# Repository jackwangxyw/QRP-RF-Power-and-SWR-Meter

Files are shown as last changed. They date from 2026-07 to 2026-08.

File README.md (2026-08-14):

# QRP RF Power and SWR Meter

This is a compact standalone power and SWR meter designed for field use. The rectifier diodes used in this design have relatively flat performance up to 50MHz, so it is able to cover all of the HF bands. It is built around the ATtiny 3224 microcontroller, so writing your own or modifying the existing code is easy. 

Render Main
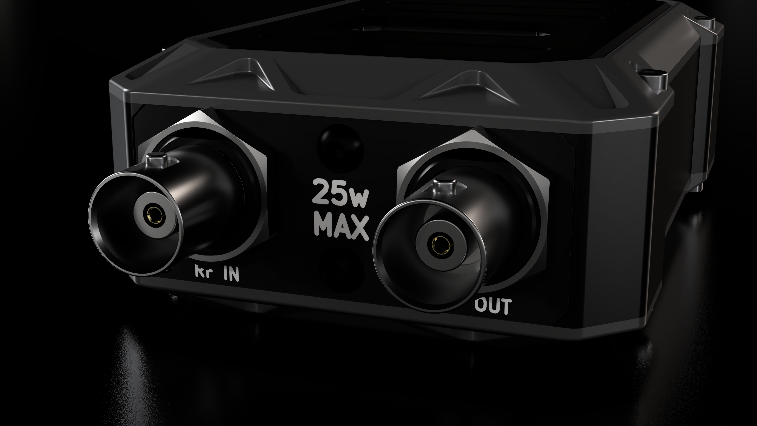
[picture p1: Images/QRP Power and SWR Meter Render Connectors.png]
Render Connectors


## Features

- Accurate Power and SWR measurements for HF + 6m
- 0.96in OLED display
  - Numerical and graph views for power and SWR
  - Peak hold indicator on power bar
- 25w max power limit
- Built in 1000mAh battery for over 40 hours of continuous use, 120 hours of realistic field use, and months on standby
- Auto dim, screen off, and standby modes, turned on by RF
- USB-C charging
  - LED turns on when charging, and will turn off when full
  - Can charge while the switch is in the off position
- Reverse polarity protection for the battery
- Watts or dBm display
- Built in calibration mode (Displays raw ADC counts, more info below)
- Basic warning features
  - When SWR or power goes over a certain threshold, that number will blink as a warning.

## Changelog
Rev 2 - Switched to the ATtiny 3224 microcontroller from the old and obsolete ATmega 328p, switched to a 4 layer board, added onboard lipo charging, connectorized the OLED, among various other small improvements.

## Usage
To use the meter, simply flip the switch to the on position, plug in your RF input and output, and you're off to the races. If you want to switch the unit for power measurements between Watts and dBm, simply short press the tactile button. When no RF is passed through the meter, the screen will dim, then turn off, then go into standby mode in intervals set in the [Code/SRC/config.h](Code/SRC/config.h) file. Passing RF through the meter will turn the screen back on and put it into active mode. (Note that the button does nothing when the screen is off.) You can also slide the switch off and back on again to put the device back into active mode as well. This feature is just an auto standby, not a true auto off, that is handled with the physical slide switch.

When the device is turned on via the switch, a splash screen shows indicating the software version and battery voltage. Then it jumps to the main screen. 

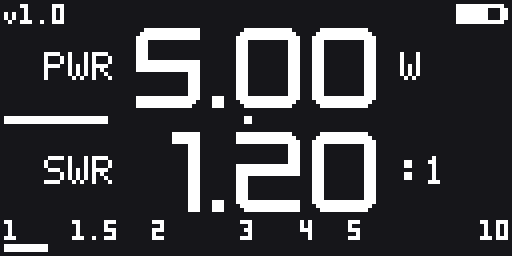
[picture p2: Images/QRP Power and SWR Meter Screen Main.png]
Main screen


## Calibration
This board has a built in calibration mode that you can enter by long pressing the tactile button on the PCB. This mode will display the raw adc counts for the VFWD and VREV that the microcontroller reads. To be clear, you **DO NOT** need to do this in normal use, the default values in the code have already been tested and are accurate. Only do this if you have the precision equipment to do so and want to gain that last 1-5% of accuracy. (That accuracy will probably be gone anyway as the diodes' responses vary with temperature and other factors anyway). You can also check the resting VFWD count of WAKE_COUNTS in [Code/SRC/config.h](Code/SRC/config.h). The default value should work, but if you notice your value is higher than the default, the device will never go into standby, so you can change that.

If you notice that your values are off by a consistent amount at every power level, you can change the CAL_OFFSET_DB in [Code/SRC/config.h](Code/SRC/config.h). (Again, this is **NOT NEEDED** for most people, only for the edge cases where that batch of diodes may be off) (Only do this if you notice something consistently wrong when comparing with precision equipment)

To calibrate the power measurements, take a RF source of known power output and frequency and plug this into the RF input, plug a dummy load into the RF output, transmit at many different power levels, record the VFWD ADC count and the power you inputted (in dBm) for every datapoint.(adc counts is x, dBm power is y) Take the values you get and input them into [Desmos](https://www.desmos.com/calculator) in a table, then run a quartic regression: y1 ~ a(log(x1))^4 + b(log(x1))^3 + c(log(x1))^2 + d·log(x1) + k. Take the a, b, c, d, and k values you obtain and input them in CAL_A through CAL_K in [Code/SRC/config.h](Code/SRC/config.h). This "calibration factor" will work for both power and SWR readings. 

There are two hard limits with this hardware. The bottom limit is set by the 1N5711 rectifier diodes. They need ~0.33 V to conduct, so below ~0.25 W, readings will be inaccurate, power levels under ~0.1 W will read as 0. The top end limit is set at an ABSOLUTE max of 28.7 W, this is due to the 2.5v adc reference and maximum of 4095 ADC counts.

If you want to test SWR, you can put loads of known resistance on the RF output to check the reported value. (Eg: 50Ω = 1:1 100Ω = 2:1, 150Ω = 3:1, etc)

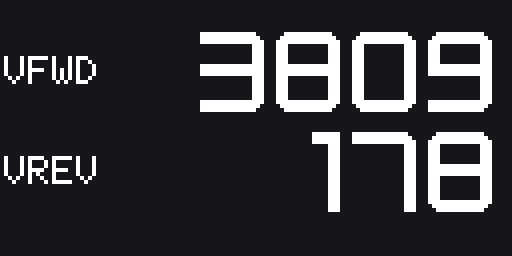
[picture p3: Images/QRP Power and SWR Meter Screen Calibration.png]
Calibration screen


## Assembly
Assembly is quite simple. All of the SMD parts are 0805 size or smaller so it is easy to hand solder without a hot plate. There are plenty of tutorials on how to do this online. Some tips that I can give are to use LOTS of flux. (Seriously, this makes life so much easier) Simply solder all of the parts onto the PCB. When you solder the connector to the OLED display, make sure to double check the pinout of your specific display and match it to the PCB silkscreen. Some of the displays may have different pinouts. 

There is also an [interactive BOM](Interactive%20BOM.html) which helps greatly with locating where parts go. Simply download the file to your computer, then simply opening the file will open up the interactive BOM in your web browser.

If you do decide to use the 3D printed case, simply put in the 8 heat set inserts on each side, and screw everything together, its pretty self explanatory. You may want to attach the battery to the top panel with some glue or double sided tape to prevent it from sliding/rattling around inside of the case.

## Programming

Programming is easy, all you need is a [UPDI programmer](https://www.adafruit.com/product/5879?srsltid=AfmBOoosIHZ5qCXL0qs-41c_Th3voxFLiswGlyJfjmZCHLlL7hfAid7V) and a computer. Simply plug the programmer into your computer, connect the programmer's 3 pins into the PCB, and use PlatformIO to flash the board. The MCU runs at 10MHz because the ATtiny is only rated for 20MHz with a VDD above 4.5 V.

For the user interface, there are two fonts available to pick from in the [Code/SRC/config.h](Code/SRC/config.h) file. You can change BIG_FONT between two font styles, choose whichever one suits your liking.

For REV 2 PCBs, the screen is software I2C because I totally missed the fact that the ATtiny supports hardware I2C and put them on the wrong pins. This works fine, but will likely be fixed in a future PCB revision.

```
cd Code
pio run            # build
pio run -t upload  # flash over UPDI
```

## Ordering PCBs
This design needs 1 or 2 pcbs depending on whether or not you build the 3D printed enclosure. You will need the Main PCB and the optional Connector Panel PCB. The gerber files found for these are in the [Gerbers Folder](Gerbers). I like to order from JLCPCB as they have good quality and are relatively cheap, I got 5 of each of these PCBs for under $20 shipped. The Main PCB is a 4 layer PCB and needs the JLC04161H-7628 stackup or similar. The connector panel is just a normal 2 layer PCB. Everything else can be the JLCPCB defaults. (You can change the solder mask color to whatever suits your preference)
## BOM
A [CSV](RF%20SWR%20and%20Power%20Meter%20BOM.csv) file is included with all of the parts, specs and links. One of these meters can be built for anywhere between $30-$50 each depending on where you live and what parts you have already and how many you decide to build.   

PCB parts:
| Reference | Qty | Value | Footprint | Recommended Part |
| :--- | :---: | :--- | :--- | :--- |
| C1, C2 | 2 | 10nF | 805 | [DigiKey Link](https://www.digikey.com/en/products/detail/kyocera-avx/KGM21NR71H103KT/563493) |
| C3, C4 | 2 | 4.7uF | 805 | [DigiKey Link](https://www.digikey.com/en/products/detail/tdk/C2012X7R1E475K125AB/2443450) |
| C5 | 1 | 0.1uF | 805 | [DigiKey Link](https://www.digikey.com/en/products/detail/kyocera-avx/KGM21NR71H104KT/563505) |
| D1, D2 | 2 | 1N5711 | SOD-123 | [DigiKey Link](https://www.digikey.com/en/products/detail/good-ark-semiconductor/GS1N5711W/18667513) |
| D3 | 1 | LED Red | 1206 | [DigiKey Link](https://www.digikey.com/en/products/detail/liteon/LTST-C150KRKT/386761) |
| IC1 | 1 | ATTINY3224 | SOIC-14 | [DigiKey Link](https://www.digikey.com/en/products/detail/microchip-technology/ATTINY3224-SSFR/17631056) |
| IC2 | 1 | MCP73831 | SOT-23-5 | [DigiKey Link](https://www.digikey.com/en/products/detail/microchip-technology/MCP73831T-2ACI-OT/964301) |
| J1, J2 | 2 | BNC Connector | Molex 0731385003 | [DigiKey Link](https://www.digikey.com/en/products/detail/molex/0731385003/3303300) |
| J3 | 1 | USBC Receptacle | GCT_USB4800-03-A | [DigiKey Link](https://www.digikey.com/en/products/detail/gct/USB4800-03-A/16688032) |
| J4 | 1 | OLED Connector | JST B4B-XH-A | [DigiKey Link](https://www.digikey.com/en/products/detail/jst-sales-america-inc/B4B-XH-A/1651047) |
| J5 | 1 | UPDI Connector | 3 Pin 2.54mm Header | [DigiKey Link](https://www.digikey.com/en/products/detail/sullins-connector-solutions/PPPC031LFBN-RC/810175) |
| J6 | 1 | Battery Connector | Molex 0530480210 | [DigiKey Link](https://www.digikey.com/en/products/detail/molex/0530480210/242864) |
| Q1 | 1 | SI2301 | SOT-23-3 | [DigiKey Link](https://www.digikey.com/en/products/detail/mcc-micro-commercial-components/SI2301-TP/1793242) |
| R1, R2, R5, R6 | 4 | Thin Film 100R 1% | 1206 | [DigiKey Link](https://www.digikey.com/en/products/detail/stackpole-electronics-inc/RNCP1206FTD100R/2240316) |
| R3, R4, R7, R8 | 4 | 10k 1% | 805 | [DigiKey Link](https://www.digikey.com/en/products/detail/vishay-dale/CRCW080510K0FKEA/1175751) |
| R9, R10 | 2 | 5.1k 1% | 805 | [DigiKey Link](https://www.digikey.com/en/products/detail/yageo/RC0805FR-075K1L/727988) |
| R11 | 1 | 1.5k | 805 | [DigiKey Link](https://www.digikey.com/en/products/detail/vishay-dale/CRCW08051K50FKEA/1175655) |
| R12 | 1 | 2k 1% | 805 | [DigiKey Link](https://www.digikey.com/en/products/detail/yageo/RC0805FR-072KL/727664) |
| R15 | 1 | 100k | 805 | [DigiKey Link](https://www.digikey.com/en/products/detail/stackpole-electronics-inc/RMCF0805FG100K/1712614) |
| SW1 | 1 | Button | TS11-674-43-BK-160-RA-D | [DigiKey Link](https://www.digikey.com/en/products/detail/same-sky-formerly-cui-devices/TS11-674-43-BK-160-RA-D/16562767) |
| SW2 | 1 | SW_SPDT | SLW-129956-4A-RA-N-D | [DigiKey Link](https://www.digikey.com/en/products/detail/same-sky-formerly-cui-devices/SLW-129956-4A-RA-N-D/24399223) |
| T1 | 1 | BN-43-202 | BN-43-202 | [Kits and Parts Link](https://toroids.info/BN-43-202.php) |

Digikey cart link: https://www.digikey.com/short/31wwbcbf  
(Certain SMD parts have more than you need, usually because buying 10 is cheaper than buying the required amount)

<br>

Other Parts:
| Part | Quantity | Link |
| :--- | :---: | :--- |
| 0.96in OLED | 1 | [Amazon Link](https://www.amazon.com/Display-SSD1306-Self-Luminous-Compatible-Raspberry/dp/B0GBWXTR1Z/ref=sr_1_13?) |
| Battery | 1 | [Amazon Link](https://www.amazon.com/dp/B0DPZVBKMY?) |
| M2.5x5mm Button Head | 5 | [Amazon Link](https://www.amazon.com/XunLiu-Button-Socket-Screws-BlackNickel/dp/B0756WTM1D/ref=sr_1_6?) |
| M2x3mm | 4 | [Amazon Link](https://www.amazon.com/uxcell-100Pcs-Socket-Button-Machine/dp/B01N76IPXI/ref=sr_1_2?) |
| M2x5mm Socket Head | 8 | [Amazon Link](https://www.amazon.com/Socket-Screws-Stainless-Thread-Spanner/dp/B0GHYKFVLC/ref=sr_1_3?) |
| M2 Threaded Inserts | 8 | [Amazon Link](https://www.amazon.com/MECCANIXITY-Threaded-Printing-Electronic-M2x3-5x4mm/dp/B0F2FRSJQN/ref=sr_1_4?) |

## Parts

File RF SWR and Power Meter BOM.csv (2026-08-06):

RF SWR and Power Meter BOM
PCB Parts:
Reference | Qty | Value | Footprint | Recomended Part:
C1,C2 | 2 | 10nF | 805 | https://www.digikey.com/en/products/detail/kyocera-avx/KGM21NR71H103KT/563493
C3,C4 | 2 | 4.7uF | 805 | https://www.digikey.com/en/products/detail/tdk/C2012X7R1E475K125AB/2443450
C5 | 1 | 0.1uF | 805 | https://www.digikey.com/en/products/detail/kyocera-avx/KGM21NR71H104KT/563505
D1,D2 | 2 | 1N5711 | SOD-123 | https://www.digikey.com/en/products/detail/good-ark-semiconductor/GS1N5711W/18667513
D3 | 1 | LED Red | 1206 | https://www.digikey.com/en/products/detail/liteon/LTST-C150KRKT/386761
IC1 | 1 | ATTINY3224 | SOIC-14 | https://www.digikey.com/en/products/detail/microchip-technology/ATTINY3224-SSFR/17631056
IC2 | 1 | MCP73831T | SOT-23-5 | https://www.digikey.com/en/products/detail/microchip-technology/MCP73831T-2ACI-OT/964301
J1,J2 | 2 | BNC Connector | Molex 0731385003 | https://www.digikey.com/en/products/detail/molex/0731385003/3303300
J3 | 1 | USBC Receptacle | GCT_USB4800-03-A | https://www.digikey.com/en/products/detail/gct/USB4800-03-A/16688032
J4 | 1 | OLED Connector | JST B4B-XH-A | https://www.digikey.com/en/products/detail/jst-sales-america-inc/B4B-XH-A/1651047
J5 | 1 | UPDI Connector | 3 Pin 2.54mm Header | https://www.digikey.com/en/products/detail/sullins-connector-solutions/PPPC031LFBN-RC/810175
J6 | 1 | Battery Connector | Molex 0530480210 | https://www.digikey.com/en/products/detail/molex/0530480210/242864
Q1 | 1 | SI2301 | SOT-23-3 | https://www.digikey.com/en/products/detail/mcc-micro-commercial-components/SI2301-TP/1793242
R1,R2,R5,R6 | 4 | Thin Film 100R 1% | 1206 | https://www.digikey.com/en/products/detail/stackpole-electronics-inc/RNCP1206FTD100R/2240316
R3,R4,R7,R8 | 4 | 10k 1% | 805 | https://www.digikey.com/en/products/detail/vishay-dale/CRCW080510K0FKEA/1175751
R9,R10 | 2 | 5.1k 1% | 805 | https://www.digikey.com/en/products/detail/yageo/RC0805FR-075K1L/727988
R11 | 1 | 1.5k | 805 | https://www.digikey.com/en/products/detail/vishay-dale/CRCW08051K50FKEA/1175655
R12 | 1 | 2k 1% | 805 | https://www.digikey.com/en/products/detail/yageo/RC0805FR-072KL/727664
R15 | 1 | 100k | 805 | https://www.digikey.com/en/products/detail/stackpole-electronics-inc/RMCF0805FG100K/1712614
SW1 | 1 | Button | TS11-674-43-BK-160-RA-D | https://www.digikey.com/en/products/detail/same-sky-formerly-cui-devices/TS11-674-43-BK-160-RA-D/16562767
SW2 | 1 | SW_SPDT | SLW-129956-4A-RA-N-D | https://www.digikey.com/en/products/detail/same-sky-formerly-cui-devices/SLW-129956-4A-RA-N-D/24399223
T1 | 1 | BN-43-202 | BN-43-202 | https://toroids.info/BN-43-202.php
Digikey link: https://www.digikey.com/short/31wwbcbf
(Certain SMD parts have more than you need, usually because buying 10 is cheaper than buying the required amount)
Other Parts:
Part | Quantity | Link
0.96in OLED | 1 | https://www.amazon.com/Display-SSD1306-Self-Luminous-Compatible-Raspberry/dp/B0GBWXTR1Z/ref=sr_1_13?
Battery | 1 | https://www.amazon.com/dp/B0DPZVBKMY?
M2.5x5mm Button Head | 5 | https://www.amazon.com/XunLiu-Button-Socket-Screws-BlackNickel/dp/B0756WTM1D/ref=sr_1_6?
M2.5x3mm | 4 | https://www.amazon.com/uxcell-100Pcs-Socket-Button-Machine/dp/B01N76IPXI/ref=sr_1_2?
M2x5mm Socket Head | 8 | https://www.amazon.com/Socket-Screws-Stainless-Thread-Spanner/dp/B0GHYKFVLC/ref=sr_1_3?
M2 Threaded Inserts | 8 | https://www.amazon.com/MECCANIXITY-Threaded-Printing-Electronic-M2x3-5x4mm/dp/B0F2FRSJQN/ref=sr_1_4?

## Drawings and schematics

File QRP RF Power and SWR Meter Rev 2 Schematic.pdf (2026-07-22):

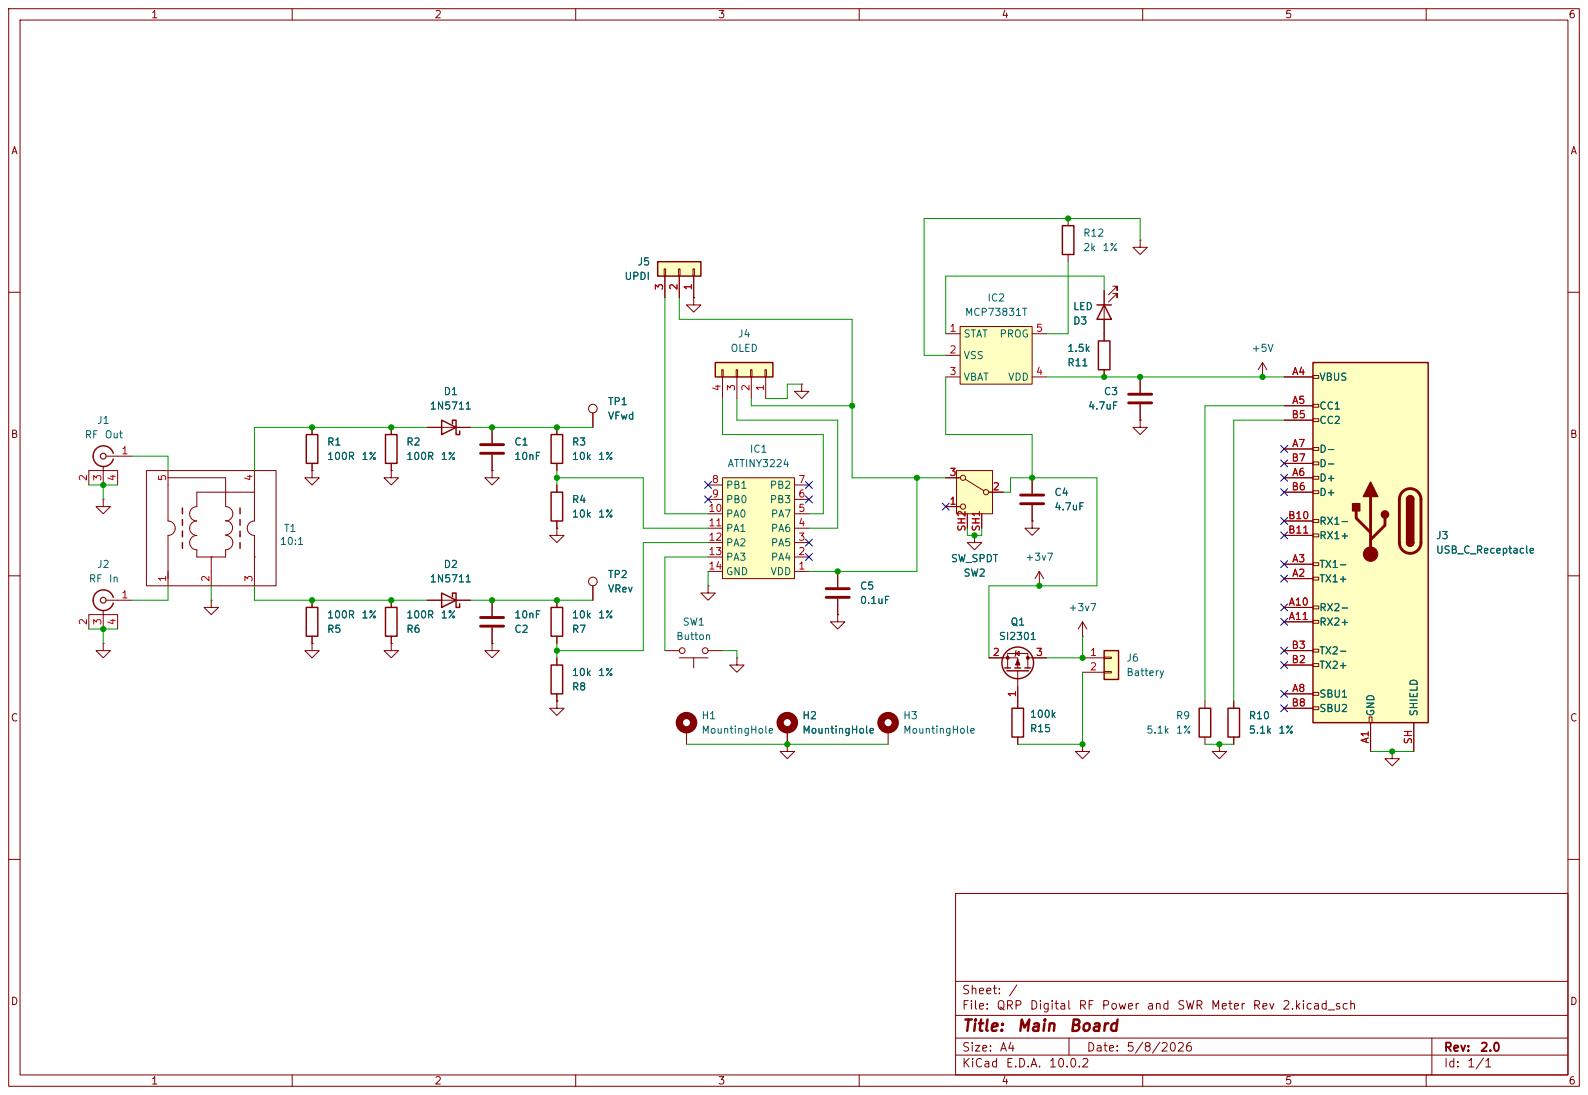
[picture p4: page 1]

Sheet: /
File: QRP Digital RF Power and SWR Meter Rev 2.kicad_sch
Title: Main Board

Size: A4 | Rev: 2.0
KiCad E.D.A. 10.0.2 | Id: 1/1

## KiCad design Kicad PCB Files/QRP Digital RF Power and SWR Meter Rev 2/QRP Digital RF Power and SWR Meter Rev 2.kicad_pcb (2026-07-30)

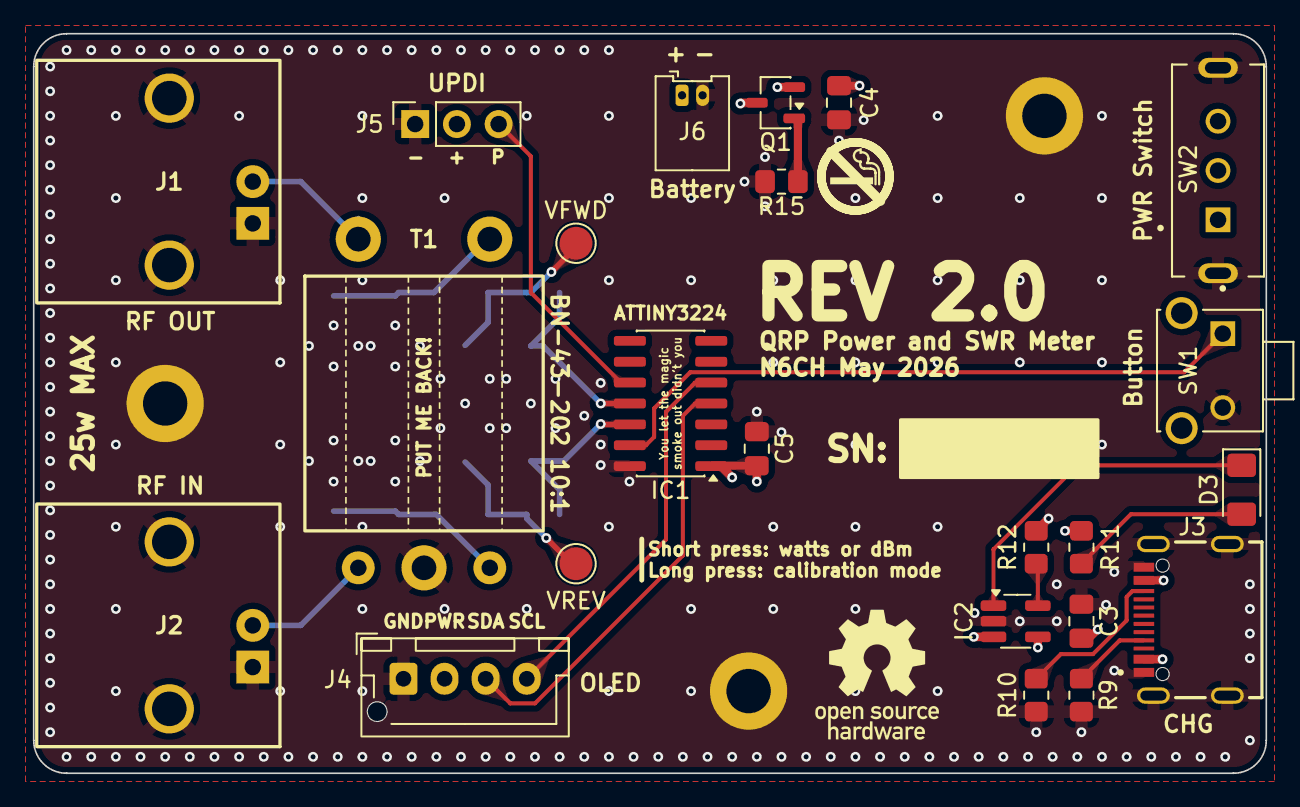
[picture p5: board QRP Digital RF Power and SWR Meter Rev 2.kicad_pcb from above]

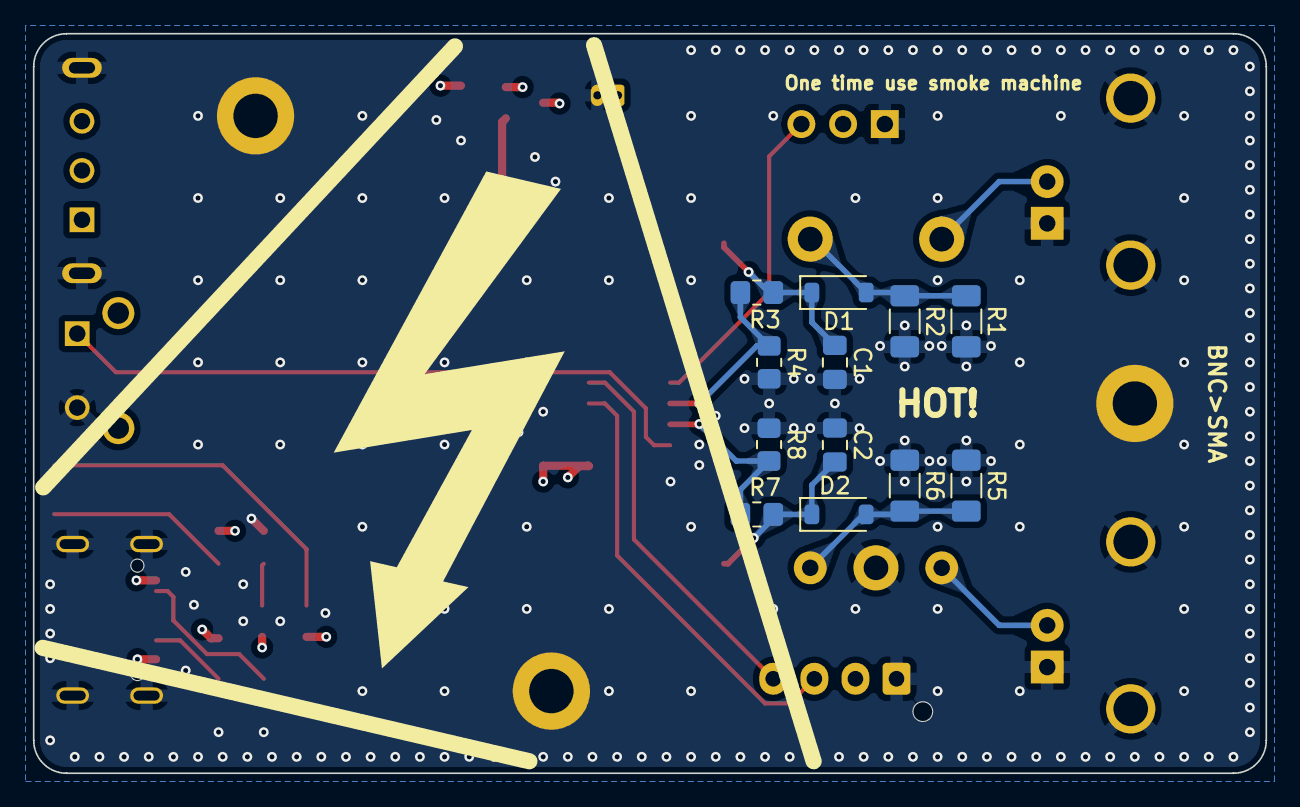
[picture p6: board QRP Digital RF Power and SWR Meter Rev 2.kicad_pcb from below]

Board: 4 copper layers, 75.0 x 45.0 mm, 38 parts (12 on the bottom side), 22 nets.

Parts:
C1, C2: 10nF; C_0805_2012Metric_Pad1.18x1.45mm_HandSolder
C3, C4: 4.7uF; C_0805_2012Metric_Pad1.18x1.45mm_HandSolder
C5: 0.1uF; C_0805_2012Metric_Pad1.18x1.45mm_HandSolder
D1, D2: 1N5711; D_SOD-123
D3: LED; LED_1206_3216Metric_Pad1.42x1.75mm_HandSolder
H1, H2, H3: MountingHole; MountingHole_2.7mm_M2.5_DIN965_Pad
IC1: ATTINY3224; SOIC-14_3.9x8.7mm_P1.27mm
IC2: MCP73831T; SOT-23-5_HandSoldering
J1: RF Out; Molex 0731385003
J2: RF In; Molex 0731385003
J3: USB_C_Receptacle; GCT_USB4800-03-A
J4: OLED; JST_XH_B4B-XH-AM_1x04_P2.50mm_Vertical
J5: UPDI; PinSocket_1x03_P2.54mm_Vertical
J6: Battery; Molex_PicoBlade_53048-0210_1x02_P1.25mm_Horizontal
Q1: SI2301; SOT-23-3
R1, R2, R5, R6: 100R 1%; R_1206_3216Metric_Pad1.30x1.75mm_HandSolder
R3, R4, R7, R8: 10k 1%; R_0805_2012Metric_Pad1.20x1.40mm_HandSolder
R9, R10: 5.1k 1%; R_0805_2012Metric_Pad1.20x1.40mm_HandSolder
R11: 1.5k; R_0805_2012Metric_Pad1.20x1.40mm_HandSolder
R12: 2k 1%; R_0805_2012Metric_Pad1.20x1.40mm_HandSolder
R15: 100k; R_0805_2012Metric_Pad1.20x1.40mm_HandSolder
SW1: Button; SW_TS11-674-43-BK-160-RA-D
SW2: SW_SPDT; SW_SLW-129956-4A-RA-N-D
T1: 10:1; BN-43-202_5Pin
VFWD: VFwd; TestPoint_Pad_D2.0mm
VREV: VRev; TestPoint_Pad_D2.0mm

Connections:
+3v7: C4.2, IC2.3 (VBAT), J6.1, Q1.2 (S), Q1.3 (D), SW2.2 (B)
+5V: C3.2, IC2.4 (VDD), J3.A4 (VBUS), R11.1
GND: C1.2, C2.1, C3.1, C4.1, C5.1, H1.1 (1_1), H2.1 (1_1), H3.1 (1_1), IC1.14 (GND), IC2.2 (VSS), J1.2 (Gnd), J1.3 (Gnd), J1.4 (Gnd), J2.2 (Gnd), J2.3 (Gnd), J2.4 (Gnd), J3.A1 (GND), J3.SH (SHIELD), J4.1, J5.1, J6.2, R1.2, R2.2, R4.2, R5.1, R6.1, R8.1, R9.2, R10.2, R12.1, R15.1, SW1.2, SW2.SH1, SW2.SH2, T1.2
unnamed: D1.2 (A), R1.1, R2.1, T1.4
unnamed: C1.1, D1.1 (K), R3.1, VFWD.1 (1_1)
unnamed: D2.2 (A), R5.2, R6.2, T1.3
unnamed: C2.2, D2.1 (K), R7.2, VREV.1 (1_1)
unnamed: D3.2 (A), R11.2
unnamed: D3.1 (K), IC2.1 (STAT)
unnamed: IC1.10 (PA0), J5.3
unnamed: IC1.11 (PA1), R3.2, R4.1
unnamed: IC1.12 (PA2), R7.1, R8.2
unnamed: IC1.13 (PA3), SW1.1
unnamed: IC1.4 (PA6), J4.3
unnamed: IC1.5 (PA7), J4.4
unnamed: C5.2, IC1.1 (VDD), J4.2, J5.2, SW2.3 (C)
unnamed: IC2.5 (PROG), R12.2
unnamed: J1.1 (In), T1.5
unnamed: J2.1 (In), T1.1
unnamed: J3.A5 (CC1), R9.1
unnamed: J3.B5 (CC2), R10.1
unnamed: Q1.1 (G), R15.2

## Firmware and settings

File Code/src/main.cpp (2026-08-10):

// ---------------------------------------------------------------------------
//  QRP RF Power and SWR Meter - Rev 2   |   N6CH
//
//  ATtiny3224. Reads the forward and reflected detectors, converts to power
//  with a quartic calibration curve, shows power, SWR and battery on a
//  128x64 SSD1306.
//
//    short press  ->  watts / dBm  (remembered in EEPROM across power cycles)
//    long press   ->  calibration mode (raw ADC counts)
//
//  Dims, blanks and finally sleeps when there is no RF; returning RF wakes it.
//  See the power management block in config.h.
//
//  Everything tunable is in config.h; everything positional is in ui.cpp.
// ---------------------------------------------------------------------------
#include <Arduino.h>
#include <avr/sleep.h>
#include <util/delay.h>
#include <math.h>

#include "config.h"
#include "ssd1306.h"
#include "ui.h"
#include "meter.h"      // pure logic, unit-tested via `pio test -e test`

#if SAVE_UNITS
  #include <EEPROM.h>
#endif

// Sleep is only correct if millis() survives standby, which needs the RTC as
// the millis source (see build_flags). If something else claims it, fail here
// rather than ship a meter whose clock stops the moment it dozes off.
#if ENABLE_SLEEP && MILLIS_TYPE != MILLIS_RTC
  #error "ENABLE_SLEEP needs -DMILLIS_USE_TIMERRTC; a TC-based millis stops in standby"
#endif

enum Screen : uint8_t { SCREEN_METER, SCREEN_CAL };

static Screen  screen   = SCREEN_METER;
static bool    dbmMode  = false;
static bool    haveOled = false;

static float fwdEnv, revEnv;          // fast envelope, drives bar + peak marker
static float fwdAvg, revAvg;          // smoothed, drives the numerals and SWR
static float peakCounts;              // highest fwd since the last frame
static float battV;
static bool  fwdErr, revErr;          // last conversion on each channel faulted

static uint32_t tSample, tFrame, tFlash;
static bool     flashOn = true;

static PeakHold     peak;
static PowerManager power;
static PowerState   pstate = PWR_ACTIVE;

// ---------------------------------------------------------------------------
//  ADC
// ---------------------------------------------------------------------------
//  analogReadEnh() with extra bits uses the ADC's own accumulator, so 16
//  samples cost one conversion sequence rather than a software loop. The
//  result is scaled back to the 12-bit domain (keeping the fraction) so the
//  calibration polynomial still takes plain 12-bit counts.
//  The core signals faults as a negative return. Reporting that as 0 counts
//  would be indistinguishable from a genuinely dead input, which is exactly the
//  reading cal mode exists to be trusted on - so latch it and let ui::cal say so.
static float readCounts(uint8_t pin, bool &err) {
    int32_t v = analogReadEnh(pin, ADC_RESOLUTION_BITS + ADC_OVERSAMPLE_BITS);
    err = (v < 0);
    if (err) return 0.0f;
    return (float)v / (float)(1 << ADC_OVERSAMPLE_BITS);
}

//  Two filters off the same conversion: a fast envelope for the bar and peak
//  marker, and a slower symmetric one for the numerals. dtMs is the real gap
//  since the last call, which is well above SAMPLE_INTERVAL_MS whenever a frame
//  is going out - hence time-driven rather than per-sample coefficients.
//
//  Below the noise floor the readout snaps rather than coasting down through its
//  time constant. The detector RC is 0.2 ms, so no signal really does mean no
//  signal, and crawling to zero over half a second just looks broken.
static void sample(uint16_t dtMs) {
    const float fwdRawC = readCounts(PIN_VFWD, fwdErr);
    const float revRawC = readCounts(PIN_VREV, revErr);

    fwdEnv = envelopeMs(fwdEnv, fwdRawC, dtMs, ENVELOPE_TAU_MS);
    revEnv = envelopeMs(revEnv, revRawC, dtMs, ENVELOPE_TAU_MS);

    fwdAvg = (fwdRawC < (float)NOISE_FLOOR_COUNTS)
           ? fwdRawC : readoutMs(fwdAvg, fwdRawC, dtMs, READOUT_TAU_MS);
    revAvg = (revRawC < (float)NOISE_FLOOR_COUNTS)
           ? revRawC : readoutMs(revAvg, revRawC, dtMs, READOUT_TAU_MS);

    // Peak capture runs at the sample rate so an SSB syllable is never missed;
    // the hold and fall happen once a frame, where the timing is intuitive.
    if (fwdEnv > peakCounts) peakCounts = fwdEnv;

    int32_t vd = analogReadEnh(ADC_VDDDIV10, ADC_RESOLUTION_BITS);
    if (vd > 0) {
        float v = (float)vd * (ADC_REF_VOLTS / (ADC_MAX_COUNTS + 1)) * 10.0f;
        battV = (battV == 0.0f) ? v : battV * 0.9f + v * 0.1f;
    }
}

// ---------------------------------------------------------------------------
//  Saved settings
// ---------------------------------------------------------------------------
//  Only the unit choice is persisted. The screen deliberately is not: cal mode
//  is a diagnostic, and booting into it because that is where you left off
//  would look like a fault.
static void loadUnits() {
#if SAVE_UNITS
    dbmMode = (EEPROM.read(EE_ADDR_UNITS) == 1);   // 0xFF (erased) -> watts
#endif
}

//  ~11 ms of stalled CPU when the byte actually changes, which is once per
//  button press and invisible next to the frame it triggers.
static void saveUnits() {
#if SAVE_UNITS
    EEPROM.update(EE_ADDR_UNITS, dbmMode ? 1 : 0);
#endif
}

// ---------------------------------------------------------------------------
//  Button
// ---------------------------------------------------------------------------
static Button button;

static void serviceButton() {
    switch (button.update(digitalRead(PIN_BUTTON) == LOW, millis())) {
    case BTN_SHORT:
        if (screen == SCREEN_METER) { dbmMode = !dbmMode; saveUnits(); tFrame = 0; }
        break;
    case BTN_LONG:
        screen = (screen == SCREEN_METER) ? SCREEN_CAL : SCREEN_METER;
        tFrame = 0;
        break;
    default:
        break;
    }
}

// ---------------------------------------------------------------------------
//  Power management
// ---------------------------------------------------------------------------
//  Nothing watches the detectors while the CPU sleeps - PA1/PA2 are ADC-only
//  and their input buffers are off - so "wake on RF" is really the PIT poking
//  us every STANDBY_PIT_PERIOD to take one reading. Under 1% duty cycle.
//
//  The PIT is free to use: megaTinyCore's RTC millis runs off RTC_CNT_vect and
//  sets RUNSTDBY, so the clock keeps counting through standby and only the
//  errata workaround touches PITCTRLA - and that is gated to non-2-series.
static void pitInit() {
    while (RTC.PITSTATUS & RTC_CTRLBUSY_bm) {}
    RTC.PITINTCTRL = RTC_PI_bm;
    RTC.PITCTRLA   = STANDBY_PIT_PERIOD | RTC_PITEN_bm;
}

ISR(RTC_PIT_vect) { RTC.PITINTFLAGS = RTC_PI_bm; }   // wake only, no work

// Sleep until the next PIT tick, then take one cheap reading. No oversampling
// and no envelope - this is a threshold test, not a measurement.
static bool standbyTick() {
    ADC0.CTRLA &= ~ADC_ENABLE_bm;
    set_sleep_mode(SLEEP_MODE_STANDBY);
    sleep_enable();
    sleep_cpu();
    sleep_disable();

    ADC0.CTRLA |= ADC_ENABLE_bm;
    _delay_us(ADC_WAKE_SETTLE_US);               // 2.5 V reference settling

    int32_t v = analogRead(PIN_VFWD);
    if (v < WAKE_COUNTS) return false;

    fwdEnv = (float)v;                           // seed so the first frame is live
    return true;
}

static void applyState(PowerState from, PowerState to) {
    if (to == from) return;
    switch (to) {
    case PWR_ACTIVE:
        if (from >= PWR_BLANK) {
            oled::displayOn(true);
            delay(OLED_WAKE_MS);                 // charge pump
            peak.init(millis());                 // never show a stale peak
            peakCounts = fwdEnv;
        }
        oled::setContrast(OLED_CONTRAST_ACTIVE);
        tFrame = 0;                              // redraw at once
        break;
    case PWR_DIM:
        oled::setContrast(OLED_CONTRAST_DIM);
        break;
    case PWR_BLANK:
    case PWR_STANDBY:
        if (from < PWR_BLANK) oled::displayOn(false);
        break;
    }
}

// ---------------------------------------------------------------------------
void setup() {
    // megaTinyCore 2.6.11 ORs the RTC prescaler group value into CTRLA
    // unshifted (timers.h, _RTC_PRESCALE_VALUE), leaving PRESCALER at DIV1 - so
    // the RTC ticks 32x fast and every millis() timeout fires 32x early.
    while (RTC.STATUS & RTC_CTRLABUSY_bm) {}
    RTC.CTRLA = RTC_RUNSTDBY_bm | RTC_PRESCALER_DIV32_gc | RTC_RTCEN_bm;

    loadUnits();        // before the first frame, so it never shows watts first

    button.init();
    pinMode(PIN_BUTTON, INPUT_PULLUP);
    pinMode(PIN_VFWD, INPUT);
    pinMode(PIN_VREV, INPUT);
    // Kill the digital input buffers on the analog pins: they burn current and
    // couple noise into the conversion when the input sits near mid-rail.
    PORTA.PIN1CTRL = (PORTA.PIN1CTRL & ~PORT_ISC_gm) | PORT_ISC_INPUT_DISABLE_gc;
    PORTA.PIN2CTRL = (PORTA.PIN2CTRL & ~PORT_ISC_gm) | PORT_ISC_INPUT_DISABLE_gc;

    analogReference(ADC_REFERENCE);
    analogReadResolution(ADC_RESOLUTION_BITS);   // the core defaults to 10
    analogSampleDuration(ADC_SAMPLE_DURATION);   // 5k source impedance

    haveOled = oled::begin();
    if (!haveOled) { delay(250); haveOled = oled::begin(); }

    fwdEnv = fwdAvg = readCounts(PIN_VFWD, fwdErr);
    revEnv = revAvg = readCounts(PIN_VREV, revErr);
    peakCounts = fwdEnv;
    sample(SAMPLE_INTERVAL_MS);

#if ENABLE_SLEEP
    pitInit();
#endif
    peak.init(millis());
    power.init(millis());

#if SPLASH_MS > 0
    if (haveOled) { ui::splash(battV); delay(SPLASH_MS); }
#endif
    power.poke(millis());                        // don't count the splash as idle
}

void loop() {
    uint32_t t = millis();

#if ENABLE_SLEEP
    // Asleep: the only thing that runs is the PIT poll. The button is not a
    // wake source by design, so it is not read here at all.
    if (pstate == PWR_STANDBY) {
        if (standbyTick()) power.poke(millis());
        else               return;
        t = millis();
    }
#endif

    // Ignore the button while blanked: it cannot bring the screen back (RF
    // only), so acting on it would silently toggle units behind a dark panel.
    if (pstate <= PWR_DIM) serviceButton();

    uint32_t dt = t - tSample;
    if (dt >= SAMPLE_INTERVAL_MS) {
        tSample = t;
        sample((uint16_t)(dt > 1000 ? 1000 : dt));   // cap after a sleep or splash
    }

    if (fwdEnv >= (float)WAKE_COUNTS) power.poke(t);
    else if (pstate <= PWR_DIM && button.stable) power.poke(t);

#if ENABLE_SLEEP
    PowerState want = power.update(t);
#else
    PowerState want = PWR_ACTIVE;
#endif
    if (haveOled) applyState(pstate, want);
    pstate = want;

    if (!haveOled || pstate >= PWR_BLANK) return;

    // Numerals, SWR and the warnings all come off the smoothed value so they
    // agree with each other; only the bar and the peak marker run off fwdEnv.
    MeterState s;
    s.dbm       = countsToDbm(fwdAvg);       // the calibrated quantity
    s.watts     = dbmToWatts(s.dbm);
    s.wattsBar  = countsToWatts(fwdEnv);
    s.swr       = computeSwr(s.watts, countsToWatts(revAvg));
    s.battVolts = battV;
    s.fwdRaw    = (uint16_t)(fwdAvg + 0.5f);
    s.revRaw    = (uint16_t)(revAvg + 0.5f);
    s.fwdErr    = fwdErr;
    s.revErr    = revErr;
    s.dbmMode   = dbmMode;

    bool warnPwr = s.watts > POWER_WARN_THRESHOLD;
    bool warnSwr = !isnan(s.swr) && (isinf(s.swr) || s.swr > SWR_WARN_THRESHOLD);
    if (screen == SCREEN_CAL) warnPwr = warnSwr = false;

    if (warnPwr || warnSwr) {
        // both blink on the same tick when both are over
        if (t - tFlash >= WARN_FLASH_MS) { tFlash = t; flashOn = !flashOn; }
    } else {
        flashOn = true;
    }
    s.blankPwr = warnPwr && !flashOn;
    s.blankSwr = warnSwr && !flashOn;

    if (t - tFrame >= FRAME_INTERVAL_MS) {
        tFrame = t;
        // Feed the frame's highest sample in, then start the next window from
        // the live envelope so the peak cannot creep upward on its own.
        s.peakFrac = peak.update(countsToWatts(peakCounts) / PWR_BAR_FULL_SCALE, t);
        peakCounts = fwdEnv;
        if (screen == SCREEN_CAL) ui::cal(s); else ui::meter(s);
    }
}

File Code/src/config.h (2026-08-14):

// ---------------------------------------------------------------------------
//  QRP RF Power and SWR Meter - Rev 2
//  Every tunable lives here. To calibrate, only CAL_A..CAL_K need touching.
// ---------------------------------------------------------------------------
#pragma once

// Everything below the pin map is plain arithmetic, so this header also
// compiles on the host for `pio test -e test`. Only the Arduino-specific
// bits are guarded.
#ifdef ARDUINO
  #include <Arduino.h>
  #include <avr/pgmspace.h>
#else
  #include <stdint.h>
#endif

#define FW_VERSION "v1.0"

// ---------------------------------------------------------------------------
//  Pin map
// ---------------------------------------------------------------------------
#ifdef ARDUINO
//  T1's winding phasing, not the layout, decides which sense port carries the
//  forward wave - and it lands opposite to the D1/D2 assignment on this board,
//  so PA2 is forward with the radio on J1. Swapped here rather than rewinding a
//  working coupler; the two detector chains are identical, so nothing else cares.
#define PIN_VFWD    PIN_PA2     // pin 12, via R7/R8 divider
#define PIN_VREV    PIN_PA1     // pin 11, via R3/R4 divider
#define PIN_BUTTON  PIN_PA3     // pin 13, SW1 to GND
// PA6 = SDA (J4.3), PA7 = SCL (J4.4) - see i2c.cpp
#endif

// ---------------------------------------------------------------------------
//  Display bus
// ---------------------------------------------------------------------------
//  Rev 2 must use software I2C: hardware TWI0 is on PB0/PB1 (unconnected) and
//  its alternate mapping is PA1/PA2, already taken by the detectors. The
//  hardware path is kept for a future board rev that routes the OLED to PB0/PB1.
#define I2C_USE_HARDWARE  0

//  Half a bit period. ~400 kHz is the practical ceiling
#define I2C_HALF_US       1

#define OLED_ADDRESS      0x3C  // 0x3D is probed automatically as a fallback

//  Panel brightness, 0x00..0xFF (SSD1306 contrast register). Drives segment
//  current, so it is most of what the display costs. DIM is what the meter
//  falls back to after SLEEP_DIM_MS with no RF.
//
//  Measured on hardware: this register saves real current but is not a usable
//  brightness control. 0x00 is unreadable and everything from 0x04 to 0x10
//  looks alike, so DIM is a power state, not a visible one. Don't bisect it
//  again - BLANK turning the panel off is the change you can actually see.
#define OLED_CONTRAST_ACTIVE  0xCF
#define OLED_CONTRAST_DIM     0x10

//  Charge pump settling after 0xAF before the panel is readable. Datasheet
//  asks for 100 ms; most modules are quicker, so this is worth trimming once
//  there is real hardware to watch.
#define OLED_WAKE_MS          100

// ---------------------------------------------------------------------------
//  Appearance
// ---------------------------------------------------------------------------
//  >>>>>>>>>>>>>>>>>>>>  NUMERAL FONT - PICK ONE  <<<<<<<<<<<<<<<<<<<<
//
//    BIG_FONT_CUSTOM     20 px tall, 2 px* monoline, 16 px cell, "25.0" = 60 px
//    BIG_FONT_MICHROMA   16 px tall, synthetic bold +1, 21 px cell, "25.0" = 70 px
//
//  Change the one line below and rebuild. Nothing else needs touching -
//  ui.cpp reads the numeral size back from the font and re-centres the
//  whole readout block to suit.
//
//  * the shipped custom set is drawn at a 3 px stroke; regenerate from
//    tools/make_digits.py to change it.

#define BIG_FONT_MICHROMA 1               // selector values - do not edit
#define BIG_FONT_CUSTOM   2

#define BIG_FONT   BIG_FONT_CUSTOM        // <-- switch here

#if BIG_FONT != BIG_FONT_MICHROMA && BIG_FONT != BIG_FONT_CUSTOM
  #error "BIG_FONT must be BIG_FONT_MICHROMA or BIG_FONT_CUSTOM"
#endif

//  >>>>>>>>>>>>>>>>>>>>>>>>>>>>>>>>>>>>>>>>>>>>>>>>>>>>>>>>>>>>>>>>>>

// Inset every element by this many pixels so nothing sits on the extreme
// edge, guarding against case/bezel alignment slop. Content is NOT shrunk -
// the rows come out of the gap between the power bar and the SWR band, and
// the SWR bar moves up off row 63. 0 restores the original layout.
#define UI_MARGIN         1

#define SHOW_POWER_BAR    1     // continuous 0..25 W bar under the power reading
#define SPLASH_MS         3000  //amount of time that splash screen stays
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

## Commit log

2026-07-22 Add BOM and Schematic
    [QRP Digital RF Power and SWR Meter Rev 2.kicad_sch, RF SWR and Power Meter BOM.csv]
2026-07-22 Renamed schematic file
2026-07-27 Updated footprint for BNC Connectors
    [QRP Digital RF Power and SWR Meter Rev 2.kicad_pcb]
2026-07-28 Add charging LED and off position charging details
2026-07-29 Update README
    Added usage and calibration instructions to README.
2026-07-30 Added Interactive BOM
    [QRP Digital RF Power and SWR Meter Rev 2.kicad_pcb]
2026-07-30 Updated Readme
    Removed duplicate calibration instructions and streamlined the programming section for clarity.
2026-08-06 Edit BOM
    [RF SWR and Power Meter BOM.csv]
2026-08-08 fixed timing bug and added cal mode debug
    [main.cpp]
2026-08-08 Fixed adc pin mixup, ramp down, and timing issue
    [config.h, main.cpp]
2026-08-08 Jitter and ramp down imporoved
    [config.h]
2026-08-10 added persistent watts/dbm mode across power cycles
